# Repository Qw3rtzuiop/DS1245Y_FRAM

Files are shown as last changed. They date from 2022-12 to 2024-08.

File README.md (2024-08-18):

# DS1245Y drop in replacement with FM28V100 FRAM

Take a look here: @braddr discovered an easier solution:
https://github.com/Qw3rtzuiop/DS1245Y_FRAM/issues/1#issuecomment-2248997533

Designed for Keithley 2001 (MEM2 option). More infos here:
https://xdevs.com/article/kei200x-mem/

Idea from TxB @eevblog forum: https://www.eevblog.com/forum/testgear/tek-csa7404-repair-project/msg1404582/#msg1404582

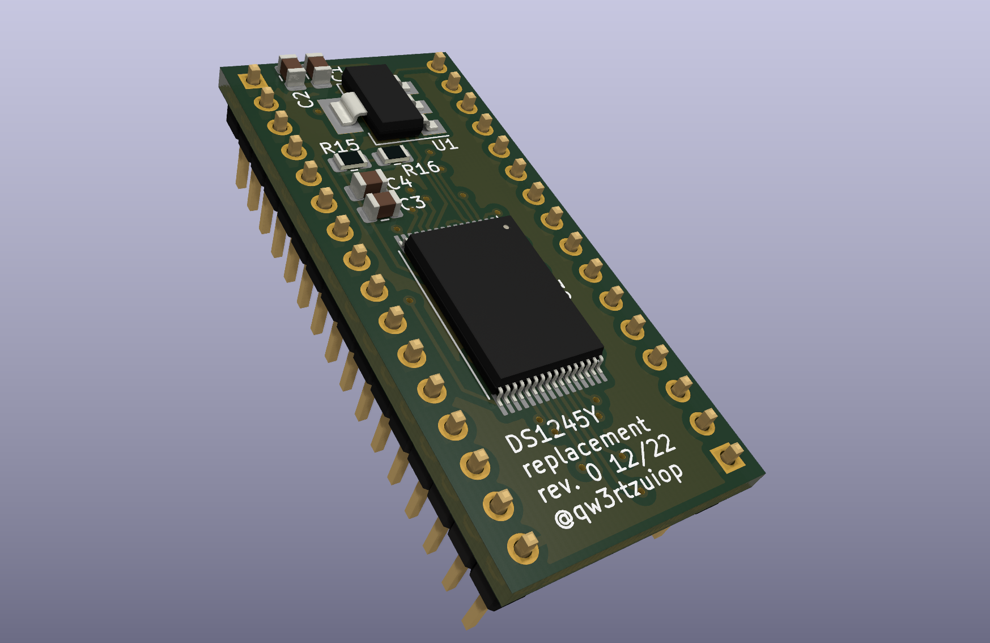
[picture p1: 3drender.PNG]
3drender


Now tested and working.

populated pcb

keithley2001

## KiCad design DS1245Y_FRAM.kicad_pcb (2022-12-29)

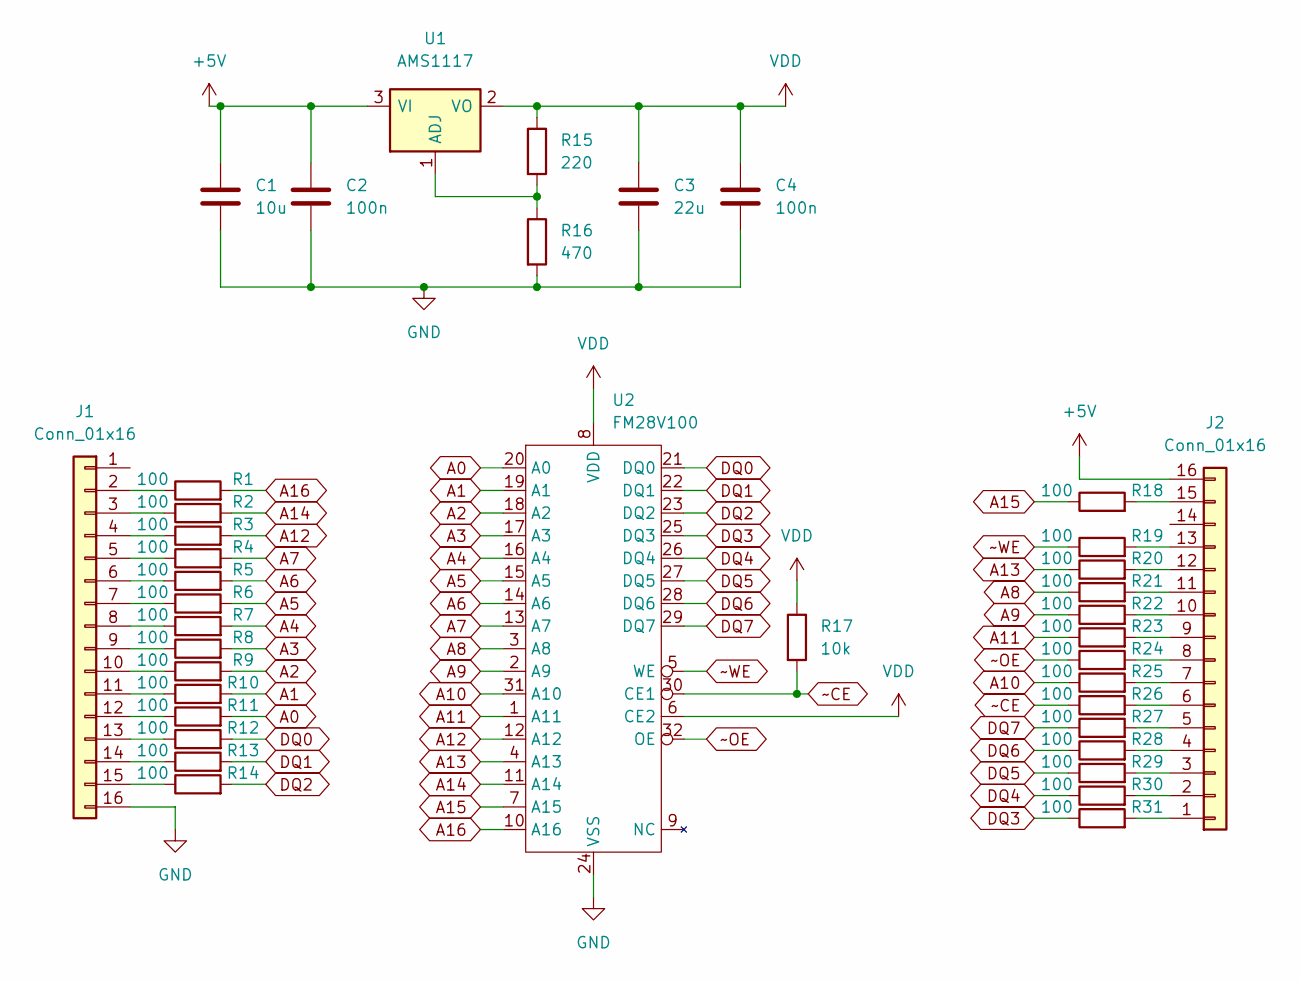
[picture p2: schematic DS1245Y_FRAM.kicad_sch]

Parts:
C1: 10u; C_0805_2012Metric
C2, C4: 100n; C_0805_2012Metric
C3: 22u; C_0805_2012Metric
J1, J2: Conn_01x16; PinHeader_1x16_P2.54mm_Vertical
R1, R2, R3, R4, R5, R6, R7, R8, R9, R10, R11, R12, R13, R14, R18, R19, R20, R21, R22, R23, R24, R25, R26, R27, R28, R29, R30, R31: 100; R_0805_2012Metric
R15: 220; R_0805_2012Metric
R16: 470; R_0805_2012Metric
R17: 10k; R_0805_2012Metric
U1: AMS1117; SOT-223-3_TabPin2
U2: FM28V100; TSOP-I-32_11.8x8mm_P0.5mm

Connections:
+5V: C1.1, C2.1, J2.16, U1.3 (VI)
A0: R11.2, U2.20 (A0)
A1: R10.2, U2.19 (A1)
A2: R9.2, U2.18 (A2)
A3: R8.2, U2.17 (A3)
A4: R7.2, U2.16 (A4)
A5: R6.2, U2.15 (A5)
A6: R5.2, U2.14 (A6)
A7: R4.2, U2.13 (A7)
A8: R21.1, U2.3 (A8)
A9: R22.1, U2.2 (A9)
A10: R25.1, U2.31 (A10)
A11: R23.1, U2.1 (A11)
A12: R3.2, U2.12 (A12)
A13: R20.1, U2.4 (A13)
A14: R2.2, U2.11 (A14)
A15: R18.1, U2.7 (A15)
A16: R1.2, U2.10 (A16)
DQ0: R12.2, U2.21 (DQ0)
DQ1: R13.2, U2.22 (DQ1)
DQ2: R14.2, U2.23 (DQ2)
DQ3: R31.1, U2.25 (DQ3)
DQ4: R30.1, U2.26 (DQ4)
DQ5: R29.1, U2.27 (DQ5)
DQ6: R28.1, U2.28 (DQ6)
DQ7: R27.1, U2.29 (DQ7)
GND: C1.2, C2.2, C3.2, C4.2, J1.16, R16.2, U2.24 (VSS)
unnamed: J1.2, R1.1
unnamed: J1.3, R2.1
unnamed: J1.4, R3.1
unnamed: J1.5, R4.1
unnamed: J1.6, R5.1
unnamed: J1.7, R6.1
unnamed: J1.8, R7.1
unnamed: J1.9, R8.1
unnamed: J1.10, R9.1
unnamed: J1.11, R10.1
unnamed: J1.12, R11.1
unnamed: J1.13, R12.1
unnamed: J1.14, R13.1
unnamed: J1.15, R14.1
unnamed: J2.1, R31.2
unnamed: J2.2, R30.2
unnamed: J2.3, R29.2
unnamed: J2.4, R28.2
unnamed: J2.5, R27.2
unnamed: J2.6, R26.2
unnamed: J2.7, R25.2
unnamed: J2.8, R24.2
unnamed: J2.9, R23.2
unnamed: J2.10, R22.2
unnamed: J2.11, R21.2
unnamed: J2.12, R20.2
unnamed: J2.13, R19.2
unnamed: J2.15, R18.2
unnamed: R15.2, R16.1, U1.1 (ADJ)
VDD: C3.1, C4.1, R15.1, R17.1, U1.2 (VO), U2.6 (CE2), U2.8 (VDD)
~CE: R17.2, R26.1, U2.30 (CE1)
~OE: R24.1, U2.32 (OE)
~WE: R19.1, U2.5 (WE)

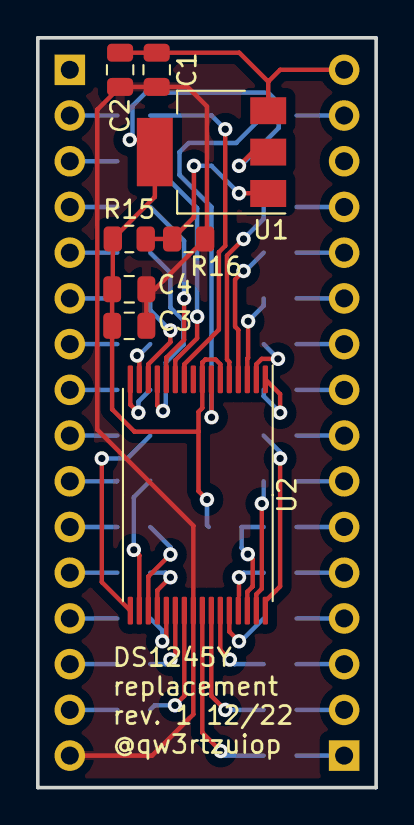
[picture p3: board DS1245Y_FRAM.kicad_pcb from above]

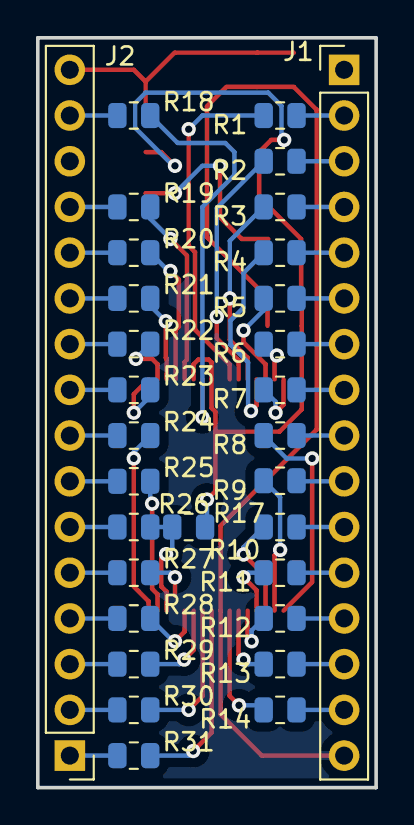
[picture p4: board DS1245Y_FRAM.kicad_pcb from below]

Board: 2 copper layers, 18.8 x 41.7 mm, 39 parts (31 on the bottom side), 60 nets.

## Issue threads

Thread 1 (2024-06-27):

Clarify that the LDO is the adjustable flavor

braddr, 2024-06-27:
I know this is an old project, but it solves a useful problem.

The 1117 ldo comes in a number of flavors, but which one isn't well specified.  As designed, this circuit seems to be looking for the adjustable version, based on the use of the resistor divider on pin 1 (ADJ) rather than straight to ground.  That said, the fram chip wants a 3.3v Vdd, and not the 3.9 that it gets with the R1 and R2 values used.  The 3.9 is above the allowed range (2.0-3.6) .  Why not remove the divider and just use the 3.3 specific flavor?  Or swap the 470 out with a 360 to get the desired 3.3.

Am I missing something?

Qw3rtzuiop, 2024-06-29:
I used the adjustable Version. The logic voltage of the Keithley is 5V. Maximum supply voltage of the FM28V100 is 4,5V. The higher supply voltage of the FM28V100 is chosen to be closer to the digital input voltage spec.

braddr, 2024-06-30:
Hrm.. According to the datasheet:
https://www.infineon.com/dgdl/Infineon-FM28V100_1_MBIT_(128K_X_8)_F-RAM_MEMORY-DataSheet-v08_00-EN.pdf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

VDD Power supply voltage minimum: 2.0,  typical: 3.3, maximum: 3.6 V

Your reasoning makes sense in terms of managing the threshold for a logical 1, but I'm concerned about running the chip over the max spec'ed voltage.  That seems to strongly suggest that a level shifter for the data and address pins is called for.  Of course, that adds cost and layout difficulties.

Qw3rtzuiop, 2024-07-03:
A level shifter would be a better solution to comply with all the specs. However it is not needed as you can see from the linked eevblog post and my experience. In the linked datasheet are the maximum ratings on top of page 6. Its 4,5.

braddr, 2024-07-24:
Apologies for not following up sooner.  I installed my FM28V100 backwards and that killed the chip (my own fault for not double checking the orientation).  In the mean while, I discovered this chip: SST39SF040.  It's a compatible drop in replacement chip for the DS1245Y.  And even better, it's only $3.99 in quantity 1 from digikey.  I ordered one and have been running it in my Keithley 2001 for a short period of time and it seems to be working fine.  So much cheaper and easier than the fram or nv ram options.

Qw3rtzuiop, 2024-07-26:
Wow that is very nice. I wasnt aware of the compatibility of the SST39SF040.

drewdoggy, 2025-03-12:
Nice find, but I can't see how this can work as a simple drop-in. The pinouts are slightly different. There surely has to be a few pin swaps?
Pin 3 to pin 31 (A15), pin 31 to pin 29 (WE#), and pin 29 to pin 3 (A14).
I think a few bodge wires and lifting those 3 pins may work.
Is there a reason you chose the SST39SF040 instead of the SST39SF010?

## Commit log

2022-12-17 kicad.gitignore aktualisiert
2022-12-17 rev. 0
    [DS1245Y_FRAM-B_Cu.gbr, DS1245Y_FRAM-B_Mask.gbr, DS1245Y_FRAM-B_Paste.gbr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]
2022-12-29 Update README.md, k2001.jpg, and pcb.jpg
2022-12-29 rev. 1
    [DS1245Y_FRAM-B_Cu.gbr, DS1245Y_FRAM-B_Mask.gbr, DS1245Y_FRAM-B_Paste.gbr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]
